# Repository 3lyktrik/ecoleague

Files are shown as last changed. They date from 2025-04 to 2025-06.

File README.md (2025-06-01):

# Ολοκληρωμένο σύστημα υποστήριξης διαγωνισμών ανακύκλωσης

Είμαστε η ομάδα **"Eco League"** από το **3ο ΓΕΛ Τρικάλων "Οδυσσέας Ελύτης"** και στα πλαίσια της συμμετοχής μας στον **"7ο Πανελλήνιο Διαγωνισμό Ανοιχτών Τεχνολογιών στην Εκπαίδευση"** υλοποιήσαμε το έργο **"Ολοκληρωμένο σύστημα υποστήριξης διαγωνισμών ανακύκλωσης"**.

## Το πρόβλημα

Ένα πολύ μεγάλο πρόβλημα των σύγχρονων κοινωνιών είναι το πρόβλημα της διαχείρισης των σκουπιδιών και της συγκέντρωσης των ανακυκλώσιμων υλικών από τους πολίτες.
Για διάφορους λόγους, πολλοί συμπολίτες μας δεν έχουν αναπτύξει κουλτούρα ανακύκλωσης και πετάνε ανακυκλώσιμα υλικά στους κοινούς κάδους απορριμμάτων, με αποτέλεσμα τόσο την περαιτέρω ρύπανση του περιβάλλοντος, όσο και τη σπατάλη πολύτιμων υλικών, που θα μπορούσαν να ξαναχρησιμοποιηθούν.

Δείτε αναλυτικά την **έρευνα** που κάναμε για αυτό το πρόβλημα στο [docs/Έρευνα.md](docs/Έρευνα.md).

## Η λύση
Για τη βελτίωση αυτής της κατάστασης υλοποιήσαμε ένα έξυπνο, αυτοματοποιημένο σύστημα υποστήριξης διαγωνισμών ανακύκλωσης.

Οι πολίτες που συμμετέχουν στο διαγωνισμό παίρνουν βαθμούς ανάλογα με τα υλικά που ανακυκλώνουν.

Τα υλικά ανιχνεύονται και καταγράφονται αυτόματα από το σύστημα, ενώ ταυτόχρονα οι ανάλογοι βαθμοί καταχωρούνται στο συγκεκριμένο πολίτη που τα ανακύκλωσε.

Κάθε ανακυκλώσιμο υλικό παίρνει συγκεκριμένους βαθμούς, οι οποίοι προστίθενται στη συνολική βαθμολογία του κάθε πολίτη.

Σε εβδομαδιαία βάση, οι πολίτες που ανακυκλώνουν τα περισσότερα υλικά και συγκεντρώνουν τη μεγαλύτερη βαθμολογία, αναδεικνύονται πρωταθλητές στην ανακύκλωση και βραβεύονται από το φορέα που διοργανώνει το διαγωνισμό.

Η ανακύκλωση γίνεται έτσι παιχνίδι, κίνητρο και διασκέδαση!

## Οι στόχοι

- Να κάνουμε την ανακύκλωση μέρος της καθημερινότητας με έναν ευχάριστο, δημιουργικό τρόπο.

- Να καλλιεργήσουμε την οικολογική συνείδηση μέσα από το παιχνίδι και τη συμμετοχή.

- Και φυσικά, να βοηθήσουμε έμπρακτα στην προστασία του περιβάλλοντος, γιατί η ανάγκη είναι μεγαλύτερη από ποτέ!

## Σχεδιασμός - Υλοποίηση

Το σύστημα αποτελείται από έξυπνους κάδους ανακύκλωσης, οι οποίοι ελέγχονται από Arduino και λειτουργούν ως εξής:

- Πρώτα γίνεται ταυτοποίηση του πολίτη με κάρτες RFID. Κάθε πολίτης προμηθεύεται μια κάρτα και αντιστοιχίζεται ο κωδικός της κάρτας με το όνομά του.
Κατόπιν γίνεται ανίχνευση του υλικού που τοποθετεί ο πολίτης στον κάδο (μέταλλο, γυαλί, πλαστικό ή άλλο υλικό) και υπολογίζονται οι βαθμοί που κερδίζει. Αρχικά, ο αισθητήρας μετάλλων ανιχνεύει τα μέταλλα. Στη συνέχεια, αν το υλικό δεν είναι μέταλλο, ενεργοποιείται το laser, το οποίο στοχεύει σε ένα φωτοκύτταρο. Αν το φωτοκύτταρο ενεργοποιηθεί, τότε το υλικό είναι διαφανές, δηλαδή γυαλί ή πλαστικό. Ενώ αν το laser δεν περάσει μέσα από το αντικείμενο, σημαίνει ότι αυτό δεν είναι διαφανές. Ο διαχωρισμός ανάμεσα στα δύο υλικά γίνεται μέσω της ζυγαριάς, καθώς το γυαλί είναι βαρύτερο από το πλαστικό.
- Μετά την ανίχνευση του υλικού, το σύστημα συνδέεται μέσω WiFi σε μια βάση δεδομένων που φτιάξαμε στο διαδίκτυο (στο ThingSpeak), όπου αποθηκεύεται η βαθμολογία κάθε πολίτη.
- Κατά τη διάρκεια της διαδικασίας εμφανίζονται όλες οι πληροφορίες σε μια οθόνη LCD.
- Παράλληλα αναπτύξαμε μια εφαρμογή για συσκευές Android, η οποία ανακτά όλες τις βαθμολογίες από τη βάση δεδομένων και εμφανίζει έναν αναλυτικό πίνακα (Hall Of Fame) με τις επιδόσεις όλων των πολιτών.

Δείτε αναλυτικά τη λύση μας, το σχεδιασμό και την υλοποίηση στο [docs/Σχεδιασμός.md](docs/Σχεδιασμός.md).

## Βίντεο
Βίντεο παρουσίασης (https://www.youtube.com/watch?v=4Vhta9W4wgw)

## Η ομάδα
Η ομάδα Eco League αποτελείται από τους μαθητές της Α΄ Τάξης του σχολείου:
Βράντζα Αθηνά, Κωτούλας Απόστολος, Παπαδάκη Δήμητρα, Παπαϊωάννου Χρήστος, Πλακιά Αναστασία, Πλεξίδας Βασίλειος, Ράπτης Αθανάσιος, Σουλιμέτσης Ελευθέριος, Στασινός Γεώργιος, Τσιγάρας Σεραφείμ, Τσιούκης Κομνηνός, Τσόγκα Νίκη και Χατζής Άγγελος.

Υπεύθυνος καθηγητής: Μαντζάνας Ευάγγελος

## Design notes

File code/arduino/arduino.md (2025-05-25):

Τα απαραίτητα αρχεία με τον κώδικα για Arduino.

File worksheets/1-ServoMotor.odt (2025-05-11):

# Φύλλο Εργασίας 1

# Κινητήρας Servo

## Δραστηριότητα 1

Μπείτε στο https://docs.arduino.cc/learn/electronics/servo-motors/ και κάντε τα παραδείγματα Knob και Sweep.

## Δραστηριότητα 2

Προγραμματίστε τον κινητήρα Servo έτσι ώστε να περιστρέφεται σε γωνία 90 μοιρών.

## Δραστηριότητα 3

Προγραμματίστε δύο συναρτήσεις με ονόματα turnServo1 και turnServo2, από τις οποίες η μία θα περιστρέφει το servo κατά περίπου 90 μοίρες, ενώ η άλλη θα το επαναφέρει στην αρχική του θέση.

### Ενδεικτική λύση:

void turnServo1(void)

{

for (int pos = 0; pos <= 120; pos++)

{

myservo.write(pos);

delay(10);

}

}

void turnServo2(void)

{

for (int pos = 120; pos >= 0; pos--)

{

myservo.write(pos);

delay(10);

}

}

## Δραστηριότητα 4

Μελετήστε τον τρόπο λειτουργίας του κινητήρα servo εδώ:

https://lastminuteengineers.com/servo-motor-arduino-tutorial/

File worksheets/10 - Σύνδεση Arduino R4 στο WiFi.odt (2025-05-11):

# Φύλλο Εργασίας 10

# Σύνδεση του Arduino UNO R4 - WiFi σε ένα ασύρματο δίκτυο

Πηγές:

1. https://docs.arduino.cc/tutorials/uno-r4-wifi/wifi-examples/#connect-with-wpa
2. https://www.halvorsen.blog/documents/technology/iot/thingspeak/thingspeak.php

Από τον παραπάνω σύνδεσμο 1, βρείτε το παράδειγμα “Connect With WPA” (μπορείτε να το ανοίξετε και από τα παραδείγματα του Arduino IDE, στη θέση: Αρχείο -> Παραδείγματα -> WiFiS3 -> ConnectWithWPA).

Στο αρχείο (ή στην καρτέλα) arduino_secrets.h πληκτρολογείστε το SSID και το password του δικού σας δικτύου WiFi.

Εκτελέστε το παράδειγμα και επαληθεύστε ότι το Arduino συνδέεται στο δίκτυο WiFi.

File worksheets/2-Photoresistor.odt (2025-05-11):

# Φύλλο Εργασίας 2

# Φωτοαντίσταση με Arduino

## Δραστηριότητα 1

Μπείτε στο https://www.circuitbasics.com/how-to-use-photoresistors-to-detect-light-on-an-arduino/

και κάντε το παράδειγμα με την αντίσταση των 220Ω.

## Δραστηριότητα 2

Μελετήστε τις τιμές που δίνει η φωτοαντίσταση (δηλαδή τις τιμές που διαβάζουμε στην αναλογική είσοδο). Προσπαθήστε να βρείτε τις οριακές τιμές της φωτοαντίστασης στο απόλυτο σκοτάδι (καλύπτοντάς την με το χέρι), ή σε έντονο φως (φωτίζοντάς την με ένα φακό). Καταγράψτε αυτές τις οριακές τιμές, όπως επίσης και την “κανονική” τιμή στον παρακάτω πίνακα.

## Δραστηριότητα 3

Συμπληρώστε ολόκληρο τον πίνακα, αλλάζοντας κατάλληλα την αντίσταση των 220Ω.

Α/Α | Αντίσταση | Τιμή που δίνει η φωτοαντίσταση σε κανονικές συνθήκες | Τιμή που δίνει η φωτοαντίσταση στο σκοτάδι | Τιμή που δίνει η φωτοαντίσταση σε έντονο φως
1 | 220Ω
2 | 1ΚΩ
3 | 2.2ΚΩ
4 | 10ΚΩ

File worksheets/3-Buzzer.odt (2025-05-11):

# Φύλλο Εργασίας 3

# Buzzer με Arduino

## Δραστηριότητα 1

Μπείτε στο https://www.ardumotive.com/how-to-use-a-buzzer-en.html και κάντε το παράδειγμα.

## Δραστηριότητα 2

Κάντε το buzzer να χτυπά πιο γρήγορα (πιο συχνά).

## Δραστηριότητα 3

Πειραματιστείτε με την τονικότητα του buzzer: κάντε το να χτυπά σε υψηλότερους ή χαμηλότερους τόνους.

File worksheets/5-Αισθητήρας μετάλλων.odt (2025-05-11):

Φύλλο Εργασίας 5

Αισθητήρας μετάλλων (επαγωγικός)

Πηγή: https://www.openbook.gr/efarmoges-arduino-sto-scholiko-ergastirio-gia-to-perivallon/

## Υλικά

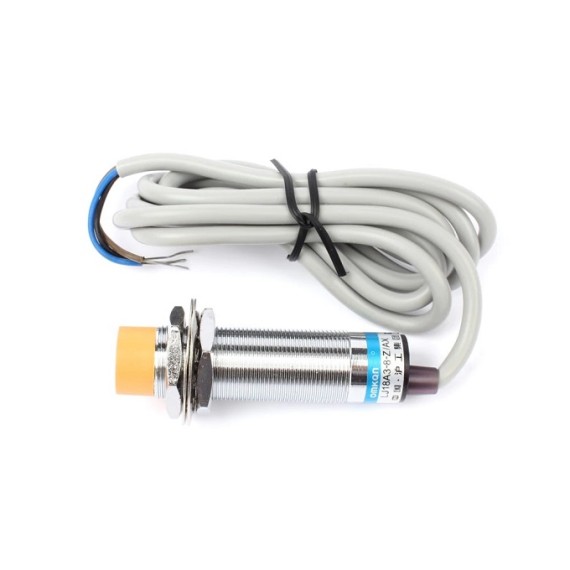
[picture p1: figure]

Επαγωγικός αισθητήρας μετάλλων LJ18A3-8-Z/AX

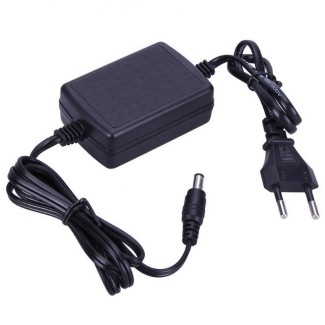
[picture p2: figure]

Τροφοδοτικό 12V

## Συνδεσμολογία

Καλώδιο αισθητήρα LJ18A3-8-Z/AX | Σύνδεση
Μπλε | Γείωση (GND). Προσοχή: η γείωση της εξωτερικής τροφοδοσίας να συνδέεται με τη γείωση του arduino.
Καφέ | 12V (από εξωτερική τροφοδοσία)
Μαύρο | Σήμα (pin 11 του Arduino, με ενεργοποιημένη την εσωτερική pull-up αντίσταση)

## Δραστηριότητα 1

Δημιουργήστε έναν ανιχνευτή μετάλλων: όταν ο αισθητήρας πλησιάσει κάποιο μέταλλο, να ανάβει το ενσωματωμένο LED του Arduino.

## Δραστηριότητα 2

Δοκιμάστε διάφορα μέταλλα (αλουμίνιο, σίδερο, ατσάλι κλπ) και σημειώστε την απόσταση από τον αισθητήρα που ανιχνεύεται το μέταλλο σε κάθε περίπτωση.

## Κώδικας

const int sensorPin = 11;

int sensorVal; // το σήμα του αισθητήρα

void setup()

{

pinMode(sensorPin, INPUT_PULLUP);

}

void loop()

{

sensorVal = digitalRead(sensorPin);

if( sensorVal == HIGH )

{

digitalWrite(LED_BUILTIN, HIGH);

}

else

{

digitalWrite(LED_BUILTIN, LOW);

}

delay(100);

}

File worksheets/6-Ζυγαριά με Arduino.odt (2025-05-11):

# Φύλλο Εργασίας 6

# Ζυγαριά με Arduino

Πηγή: https://randomnerdtutorials.com/arduino-load-cell-hx711/

## Υλικά

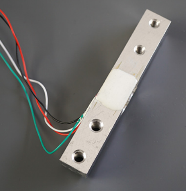
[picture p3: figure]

Αισθητήρας φορτίου (load cell)

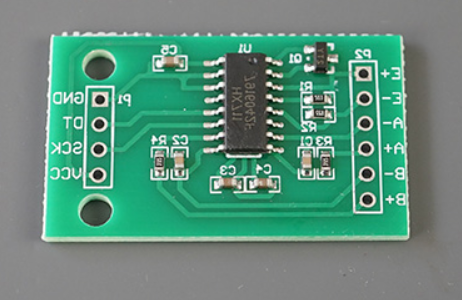
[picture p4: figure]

Ενισχυτής φορτίου HX711

## Κατασκευή ζυγαριάς

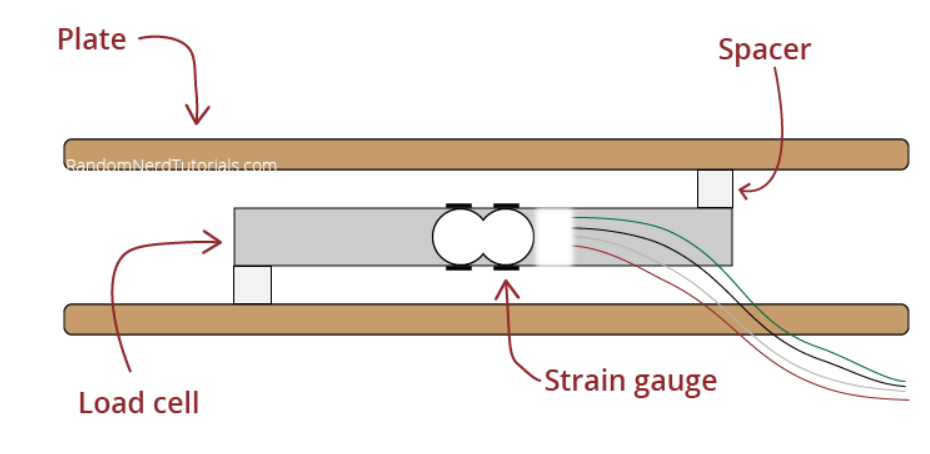
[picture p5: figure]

## Συνδεσμολογία

Αισθητήρας φορτίου | HX711 | HX711 | Arduino
Κόκκινο (Ε+) | Ε+ | GND | GND
Μαύρο (Ε-) | Ε- | DT | Pin 2
Άσπρο (Α-) | Α- | SCK | Pin 3
Πράσινο (Α+) | Α+ | VCC | 5V

## Κύκλωμα

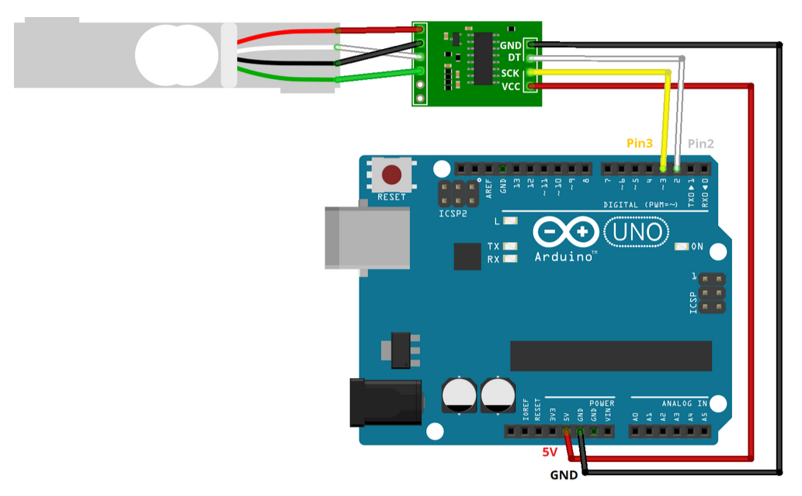
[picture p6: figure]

## Βιβλιοθήκη

Στο Arduino IDE εγκαταστήστε τη βιβλιοθήκη “HX711 Arduino Library” του Bogdan Necula.

## Πρόγραμμα για καλιμπράρισμα

// Calibrating the load cell

#include "HX711.h"

// HX711 circuit wiring

const int LOADCELL_DOUT_PIN = 2;

const int LOADCELL_SCK_PIN = 3;

HX711 scale;

void setup()

{

Serial.begin(115200);

scale.begin(LOADCELL_DOUT_PIN, LOADCELL_SCK_PIN);

}

void loop()

{

if (scale.is_ready())

{

scale.set_scale();

Serial.println("Καλιμπράρισμα Ζυγαριάς");

Serial.println("Απόβαρο... Αδειάστε τη ζυγαριά.");

delay(5000);

scale.tare();

Serial.println("Απόβαρο ρυθμίστηκε.");

Serial.println("Τοποθετήστε ένα γνωστό βάρος στη ζυγαριά...");

delay(5000);

long reading = scale.get_units(10);

Serial.print("Αποτέλεσμα: ");

Serial.println(reading);

Serial.println("Συντελεστής = (αποτέλεσμα) / (γνωστό βάρος)");

Serial.println();

}

else

{

Serial.println("HX711 δεν βρέθηκε.");

}

delay(1000);

}

## Πρόγραμμα ζυγαριάς

#include "HX711.h"

// HX711 circuit wiring

const int LOADCELL_DOUT_PIN = 2;

const int LOADCELL_SCK_PIN = 3;

HX711 scale;

void setup()

{

Serial.begin(115200);

Serial.println("Ζυγαριά");

scale.begin(LOADCELL_DOUT_PIN, LOADCELL_SCK_PIN);

// ο παρακάτω συντελεστής υπολογίστηκε με το καλιμπράρισμα

scale.set_scale(1095.56);

scale.tare(); // reset the scale to 0

delay(1000);

}

void loop()

{

if (scale.is_ready())

{

Serial.print("Βάρος (σε gr):\t");

Serial.println(scale.get_units(), 1);

}

else

{

Serial.println("Το HX711 δεν βρέθηκε.");

}

delay(3000);

}

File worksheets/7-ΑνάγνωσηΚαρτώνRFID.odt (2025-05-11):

# Φύλλο Εργασίας 7

# Ανάγνωση - Εγγραφή Καρτών RFID

Πηγή: https://lastminuteengineers.com/how-rfid-works-rc522-arduino-tutorial/

## Υλικά

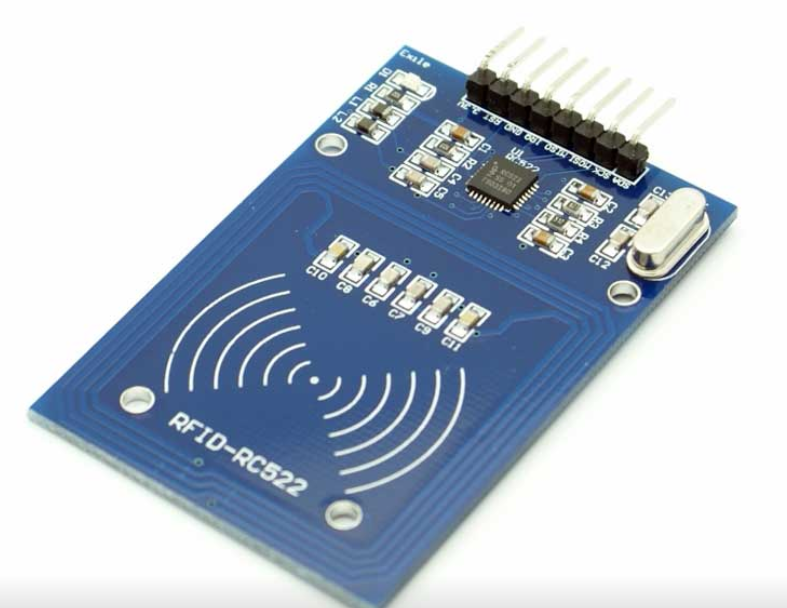
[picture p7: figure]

Αναγνώστης RFID - MFRC-522

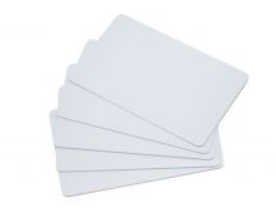
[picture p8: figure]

Κάρτες RFID 13.56MHz

## Συνδεσμολογία

RC522 πλακέτα | Arduino
Vcc | 3.3V
GND | GND
RST | Pin 5
MISO / SCL / Tx | Pin 12
MOSI | Pin 11
SCK | Pin 13
SS / SDA / Rx | Pin 10

## Κύκλωμα

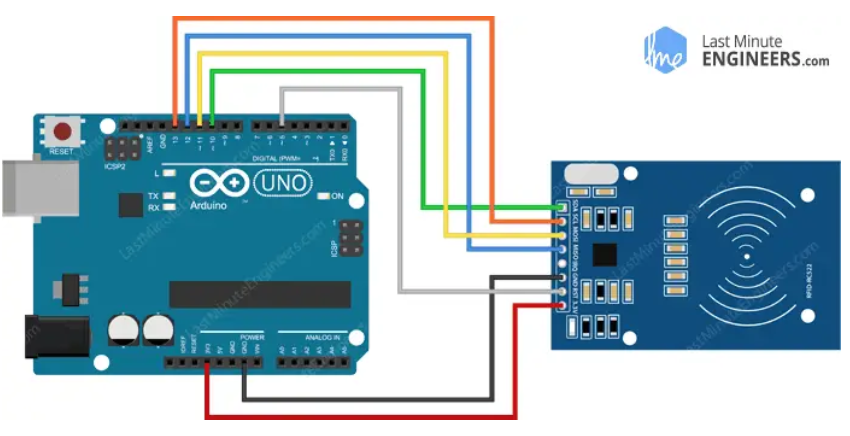
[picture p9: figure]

## Βιβλιοθήκη

Στο Arduino IDE εγκαταστήστε τη βιβλιοθήκη MFRC522 by GithubCommunity.

## Πρόγραμμα 1: Ανάγνωση όλων των δεδομένων από την κάρτα

#include <SPI.h>

#include <MFRC522.h>

#define RST_PIN 5

#define SS_PIN 10

MFRC522 mfrc522(SS_PIN, RST_PIN);

void setup()

{

Serial.begin(115200); // για serial monitor

while (!Serial); // Do nothing if no serial port is opened

SPI.begin(); // Init SPI bus

mfrc522.PCD_Init(); // Init MFRC522 card reader

delay(4);

mfrc522.PCD_DumpVersionToSerial(); // Show details of MFRC522

Serial.println("Scan PICC to see UID, SAK, type, and data blocks...");

}

void loop()

{

// Check for new card present on the reader.

if ( ! mfrc522.PICC_IsNewCardPresent() )

return;

// Select one of the cards

if ( ! mfrc522.PICC_ReadCardSerial() )

return;

// Dump debug info about the card; PICC_HaltA() is automatically called

mfrc522.PICC_DumpToSerial(&(mfrc522.uid));

}

## Πρόγραμμα 2: Έλεγχος πρόσβασης με κάρτες RFID

#include <SPI.h>

#include <MFRC522.h>

#define RST_PIN 5

#define SS_PIN 10

byte readCard[4];

String MasterTag = "931A9628"; // REPLACE this Tag ID with your Tag ID!!!

String tagID = "";

MFRC522 mfrc522(SS_PIN, RST_PIN);

void setup()

{

Serial.begin(115200); // Serial monitor

SPI.begin(); // SPI bus

mfrc522.PCD_Init(); // MFRC522

Serial.println(" -- Access Control -- ");

Serial.print("MasterTag:");

Serial.println(MasterTag);

Serial.println("Scan Your Card>>>");

}

void loop()

{

// Wait until new tag is available

while( getID() )

{

if( tagID == MasterTag )

{

Serial.println("Access Granted!");

}

else

{

Serial.println("Access Denied...");

}

Serial.print("ID: ");

Serial.println(tagID);

delay(500);

Serial.println(" -- Access Control -- ");

Serial.print("MasterTag:");

Serial.println(MasterTag);

Serial.println("Scan Your Card>>>");

}

}

// Read new tag if available

boolean getID()

{

// Getting ready for Reading PICCs

if( !mfrc522.PICC_IsNewCardPresent() )

{

return false;

}

if( !mfrc522.PICC_ReadCardSerial() )

{

return false;

}

tagID = "";

for( int i = 0; i < mfrc522.uid.size; i++ )

{

tagID.concat(String(mfrc522.uid.uidByte[i], HEX)); // Adds the bytes in a single String variable

}

tagID.toUpperCase();

mfrc522.PICC_HaltA(); // Stop reading

return true;

}

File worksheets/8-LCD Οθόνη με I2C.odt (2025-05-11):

Φύλλο Εργασίας 8

Οθόνη LCD με σύνδεση I2C

Δραστηριότητα

Κάντε το tutorial https://lastminuteengineers.com/i2c-lcd-arduino-tutorial/

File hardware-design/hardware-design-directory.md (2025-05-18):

Εδώ βρίσκονται τα σχέδια του κυκλώματος και των αντικειμένων 3D.

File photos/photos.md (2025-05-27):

## Φωτογραφίες από τη δημιουργία του έργου.
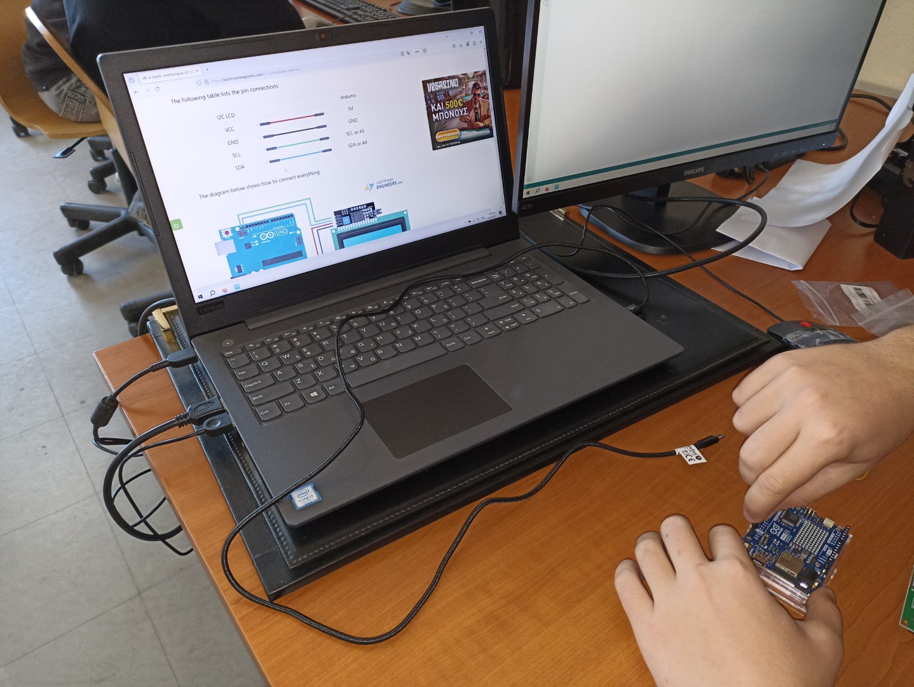
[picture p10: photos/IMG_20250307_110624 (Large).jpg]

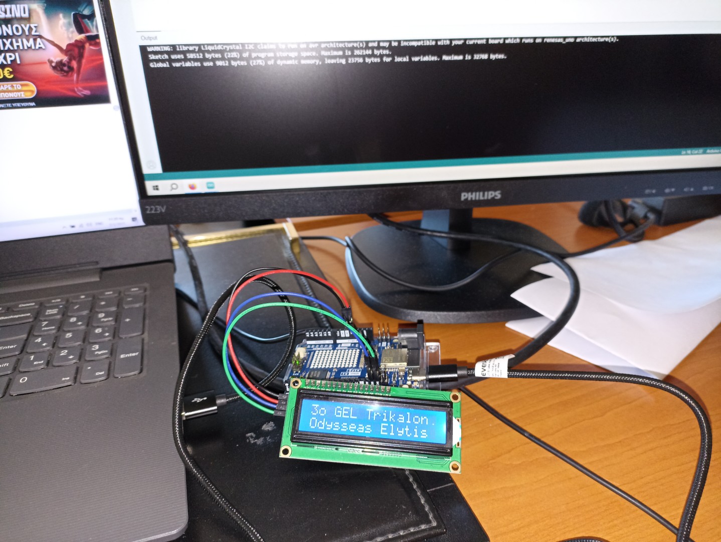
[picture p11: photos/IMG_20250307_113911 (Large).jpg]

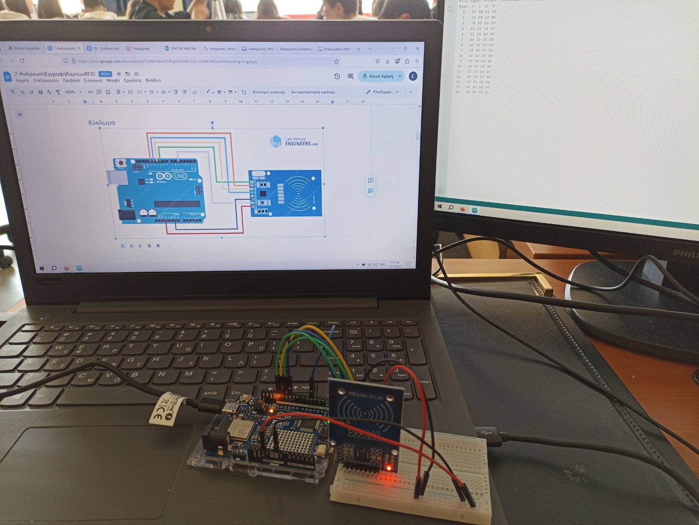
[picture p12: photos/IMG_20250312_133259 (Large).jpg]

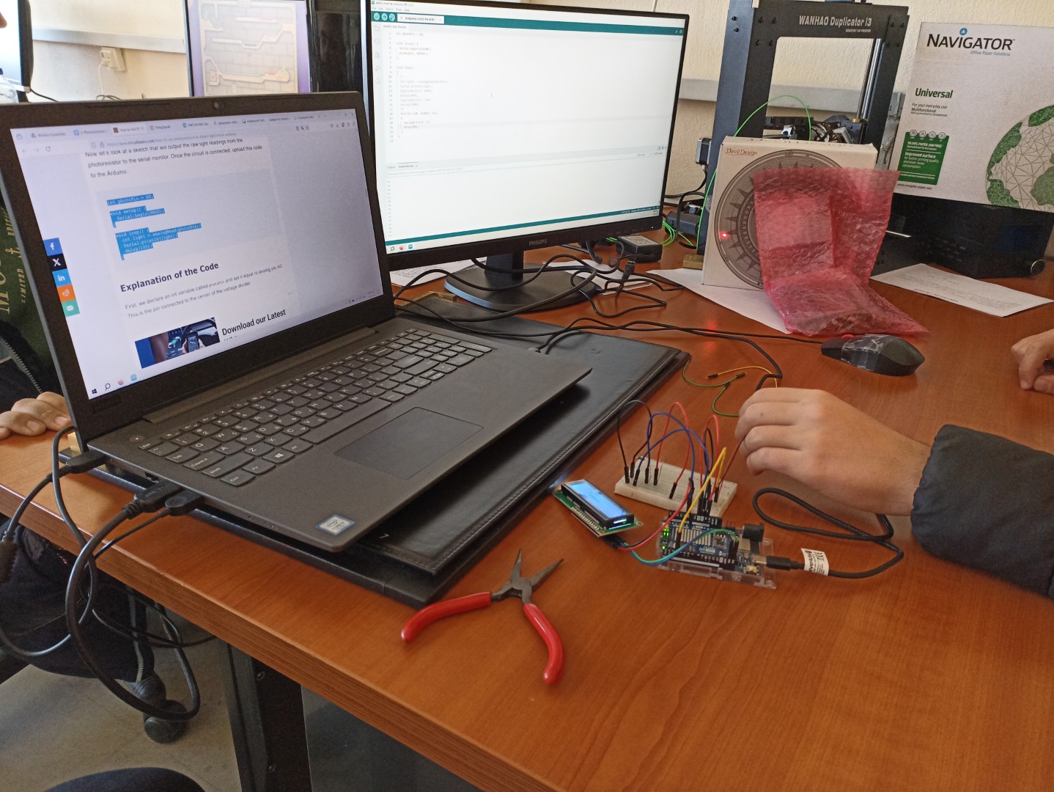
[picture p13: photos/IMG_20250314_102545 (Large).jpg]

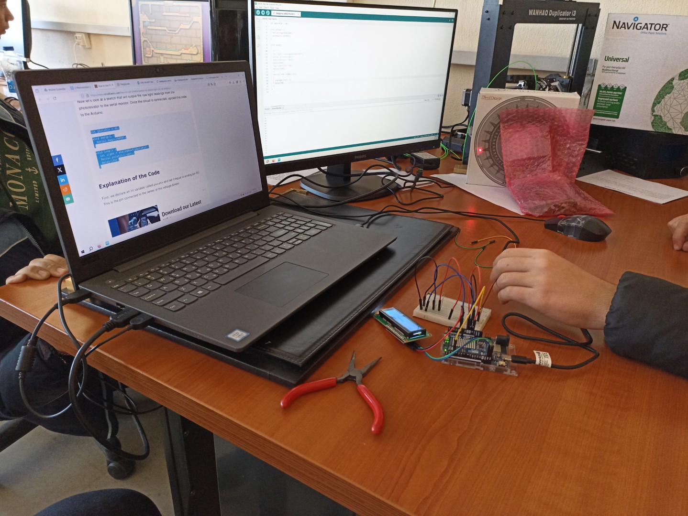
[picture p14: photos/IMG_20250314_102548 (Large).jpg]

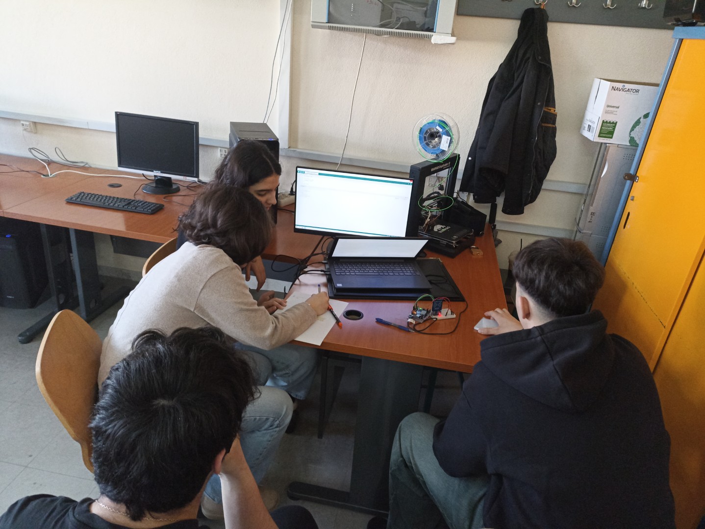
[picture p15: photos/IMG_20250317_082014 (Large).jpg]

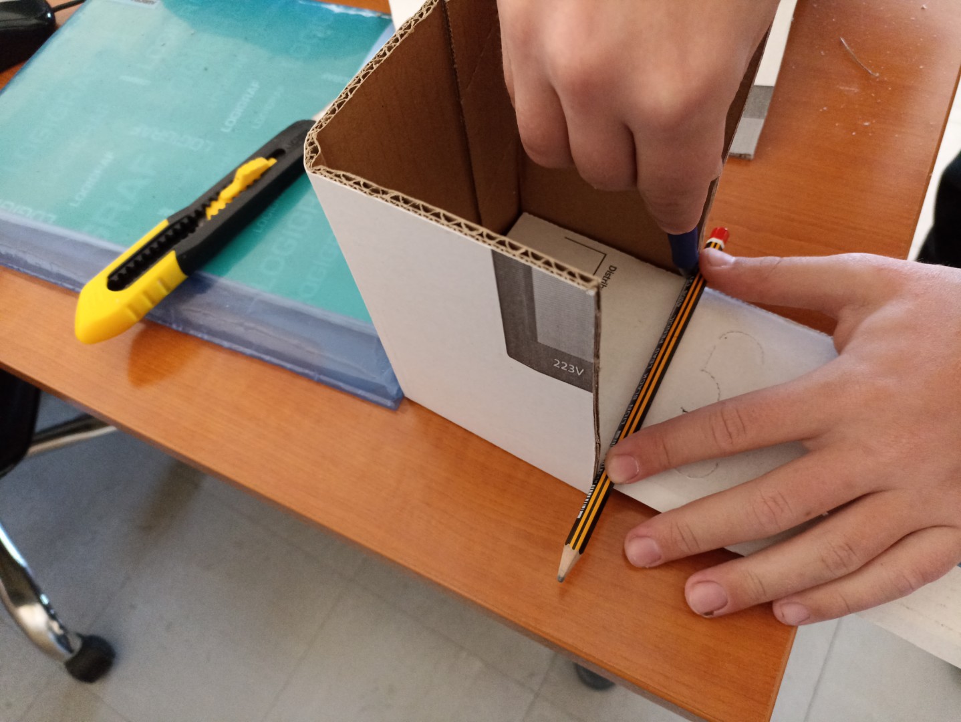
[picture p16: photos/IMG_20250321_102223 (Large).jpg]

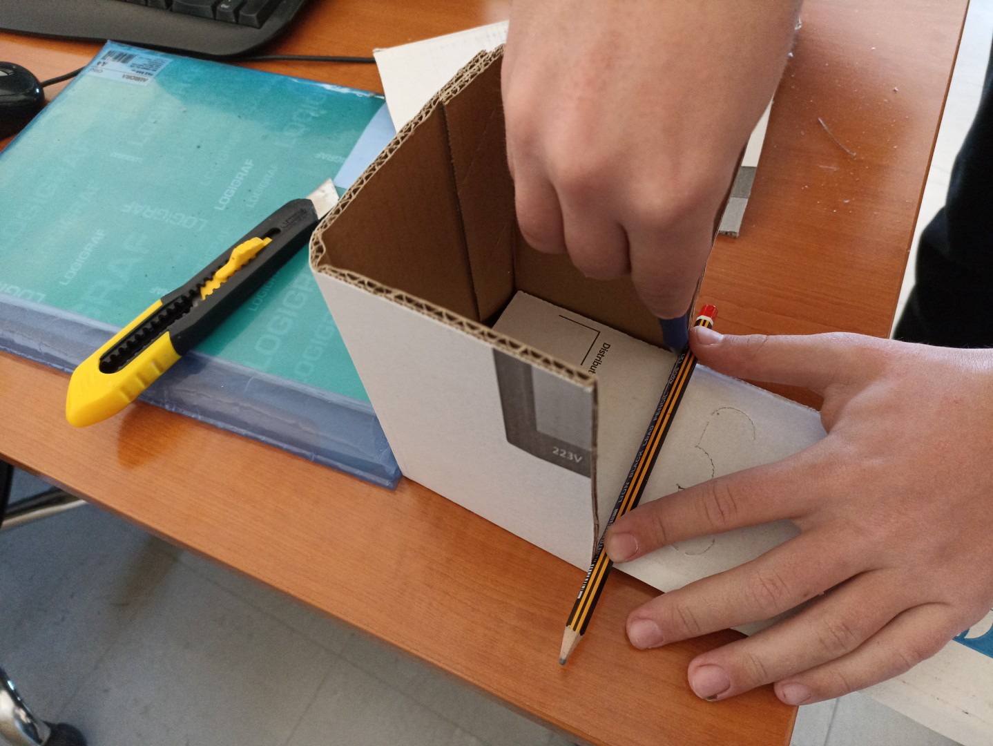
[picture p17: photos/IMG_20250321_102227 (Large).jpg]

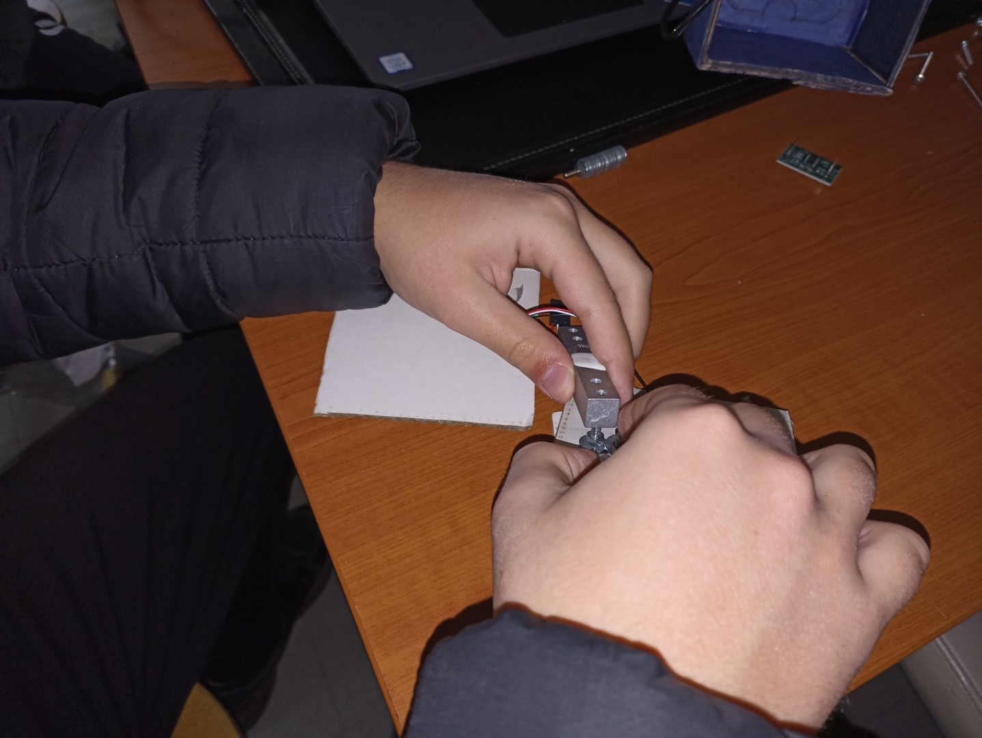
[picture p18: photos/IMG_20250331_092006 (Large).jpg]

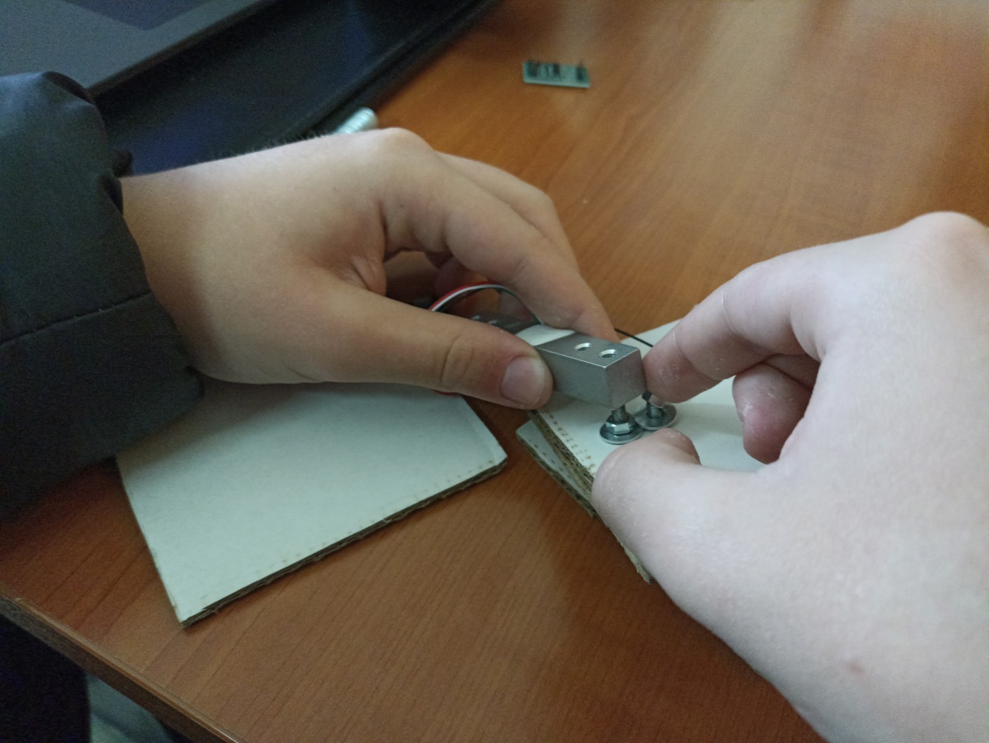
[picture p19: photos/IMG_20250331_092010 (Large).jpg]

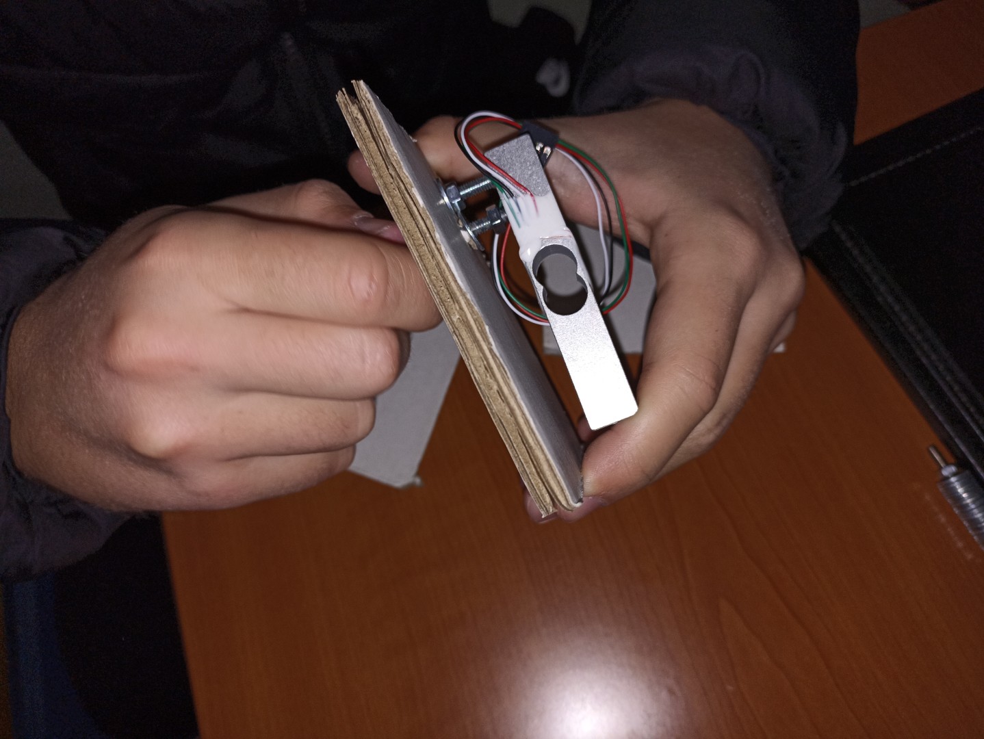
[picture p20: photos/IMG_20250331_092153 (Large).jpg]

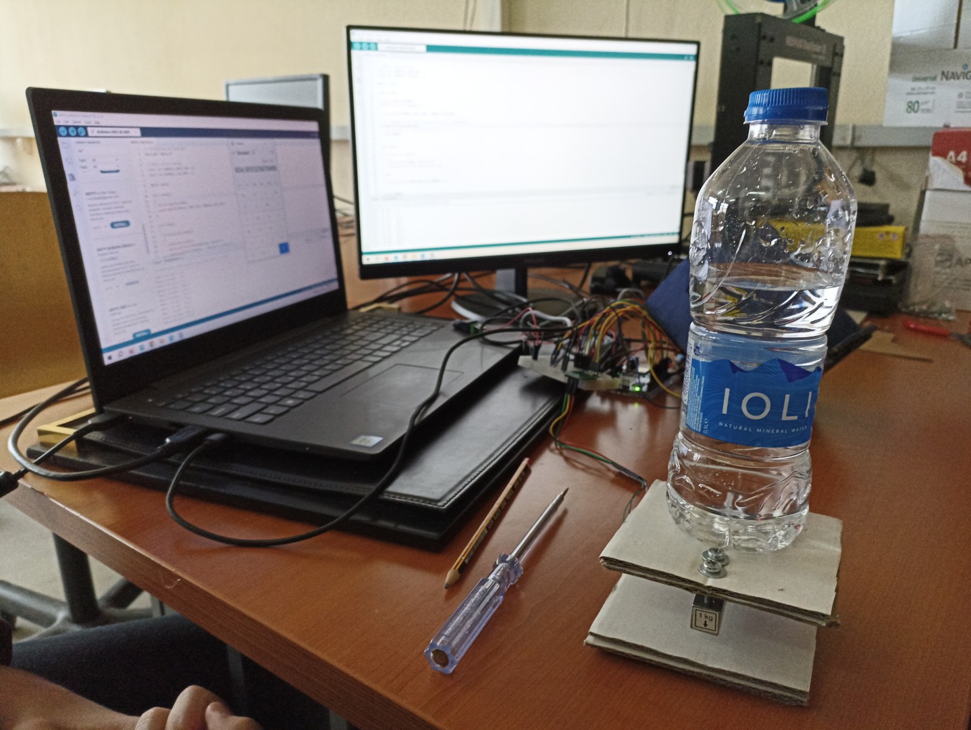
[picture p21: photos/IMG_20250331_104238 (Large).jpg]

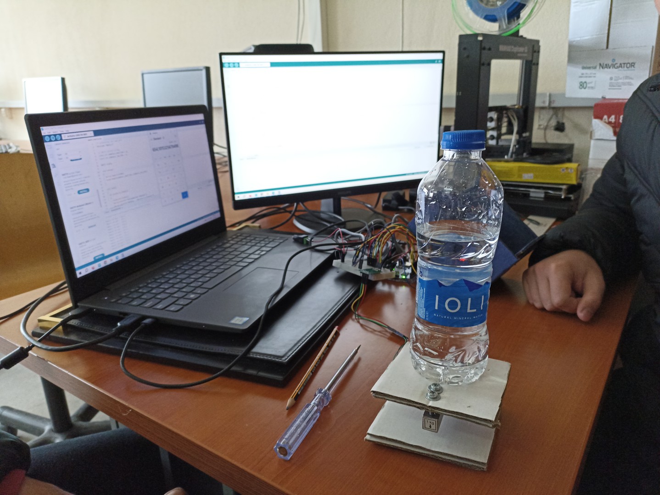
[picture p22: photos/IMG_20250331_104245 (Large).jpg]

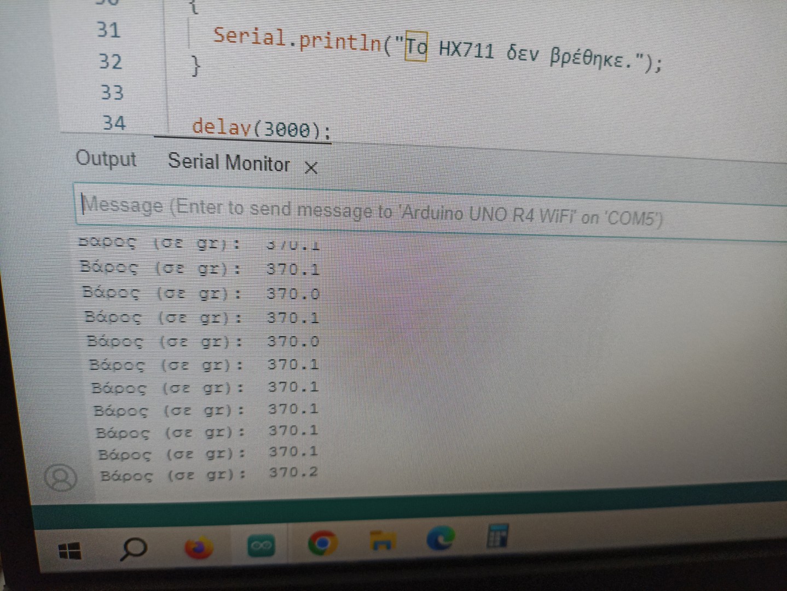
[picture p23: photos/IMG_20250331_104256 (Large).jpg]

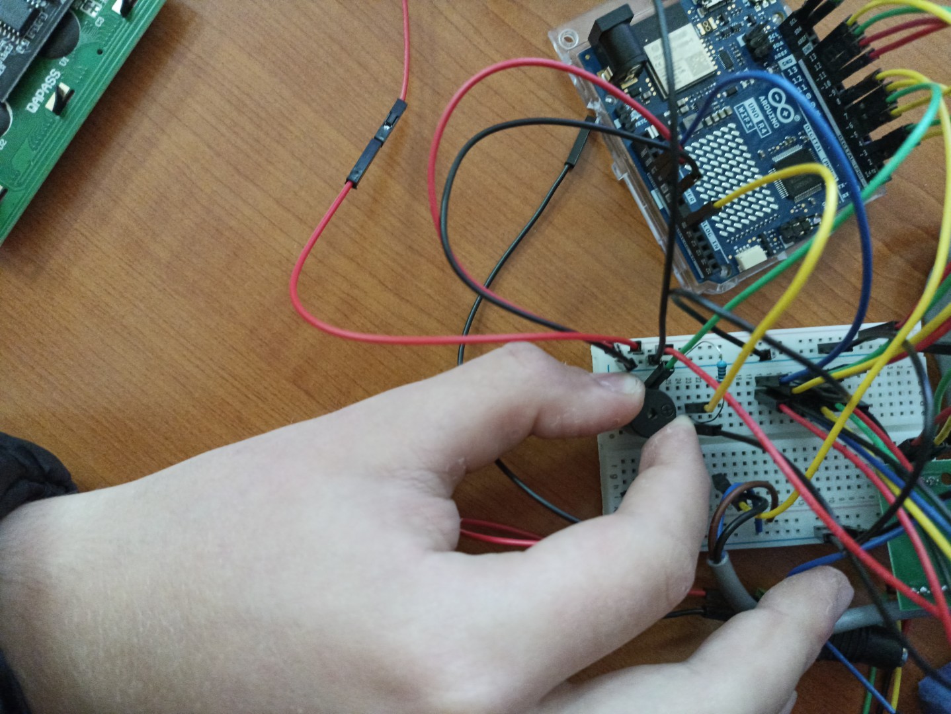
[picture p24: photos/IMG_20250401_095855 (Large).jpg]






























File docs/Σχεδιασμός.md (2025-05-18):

# Σχεδιασμός

## Σαφής ορισμός προτεινόμενης λύσης

### Λύση

Για την αύξηση της συμμετοχής των πολιτών στην ανακύκλωση, υλοποιήσαμε ένα έξυπνο, αυτοματοποιημένο σύστημα υποστήριξης διαγωνισμών ανακύκλωσης.

Οι πολίτες που θα συμμετέχουν στο διαγωνισμό ανακύκλωσης, παίρνουν βαθμούς ανάλογα με τα υλικά που ανακυκλώνουν.

Τα υλικά ανιχνεύονται και καταγράφονται αυτόματα από το σύστημα, ενώ ταυτόχρονα οι ανάλογοι βαθμοί καταχωρούνται στο συγκεκριμένο πολίτη που τα ανακύκλωσε.

Κάθε ανακυκλώσιμο υλικό παίρνει συγκεκριμένους βαθμούς, οι οποίοι προστίθενται στη συνολική βαθμολογία του κάθε πολίτη.

Σε εβδομαδιαία βάση, οι πολίτες που ανακυκλώνουν τα περισσότερα υλικά και συγκεντρώνουν τη μεγαλύτερη βαθμολογία, αναδεικνύονται πρωταθλητές στην ανακύκλωση και βραβεύονται από το φορέα που διοργανώνει το διαγωνισμό.

### Οι στόχοι

-   Να κάνουμε την ανακύκλωση μέρος της καθημερινότητας με έναν ευχάριστο, δημιουργικό τρόπο.

-   Να καλλιεργήσουμε την οικολογική συνείδηση μέσα από το παιχνίδι και τη συμμετοχή.

-   Και φυσικά, να βοηθήσουμε έμπρακτα στην προστασία του περιβάλλοντος, γιατί η ανάγκη είναι μεγαλύτερη από ποτέ!

### Σχεδιασμός - Υλοποίηση

Το σύστημα αποτελείται από έξυπνους κάδους ανακύκλωσης, οι οποίοι ελέγχονται από Arduino και λειτουργούν ως εξής:

1.  Πρώτα γίνεται ταυτοποίηση του πολίτη με κάρτες RFID. Κάθε πολίτης προμηθεύεται μια κάρτα και αντιστοιχίζεται ο κωδικός της κάρτας με το όνομά του.

2.  Κατόπιν γίνεται ανίχνευση του υλικού που τοποθετεί ο πολίτης στον κάδο (μέταλλο, γυαλί, πλαστικό ή άλλο υλικό) και υπολογίζονται οι βαθμοί που κερδίζει. Ορίσαμε 50 βαθμούς για τα μέταλλα, 40 για τα πλαστικά και 30 για το γυαλί. Για την ανίχνευση, αρχικά ο αισθητήρας μετάλλων ανιχνεύει τα μέταλλα. Στη συνέχεια, αν το υλικό δεν είναι μέταλλο, ενεργοποιείται το laser, το οποίο στοχεύει σε ένα φωτοκύτταρο (το laser με το φωτοκύτταρο πρέπει να είναι ευθυγραμμισμένα). Αν το φωτοκύτταρο ενεργοποιηθεί, τότε το υλικό είναι διαφανές, δηλαδή γυαλί ή πλαστικό. Ενώ αν το laser δεν περάσει μέσα από το αντικείμενο, σημαίνει ότι αυτό δεν είναι διαφανές. Ο διαχωρισμός ανάμεσα στα δύο υλικά γίνεται μέσω της ζυγαριάς, καθώς το γυαλί είναι βαρύτερο από το πλαστικό. Θέσαμε ως όριο τα 100gr: πάνω από 100gr θεωρείται γυαλί, αλλιώς πλαστικό.

3.  Μετά την ανίχνευση του υλικού, το σύστημα συνδέεται μέσω WiFi σε μια βάση δεδομένων που φτιάξαμε στο διαδίκτυο (στο ThingSpeak), όπου αποθηκεύεται η βαθμολογία κάθε πολίτη. Το σύστημα διαβάζει την τρέχουσα βαθμολογία του πολίτη, προσθέτει τους βαθμούς ανακύκλωσης ανάλογα με το υλικό και στέλνει τη νέα βαθμολογία πάλι στη βάση δεδομένων.

4.  Κατά τη διάρκεια της διαδικασίας εμφανίζονται όλες οι πληροφορίες (το όνομα του πολίτη, οι βαθμοί από το υλικό που ανακύκλωσε, καθώς και οδηγίες) σε μια οθόνη LCD.

Παράλληλα αναπτύξαμε μια εφαρμογή για συσκευές Android, η οποία ανακτά όλες τις βαθμολογίες από τη βάση δεδομένων και εμφανίζει έναν αναλυτικό πίνακα (Hall Of Fame) με τις επιδόσεις όλων των πολιτών.

## Πρωτοτυπία της λύσης μας

Η λύση μας ξεχωρίζει γιατί **συνδυάζει τρεις βασικούς άξονες που δεν
συναντώνται συνήθως μαζί** σε υπάρχοντα συστήματα ανακύκλωσης:

1.  **Αυτοματοποιημένη αναγνώριση ανακυκλώσιμων υλικών:**\
    Το σύστημά μας χρησιμοποιεί έξυπνες τεχνολογίες (π.χ. μέτρηση βάρους, ανίχνευση διαφάνειας, ταυτοποίηση με κάρτες) ώστε να καταγράφει **αυτόματα** τα υλικά χωρίς την ανάγκη **χειροκίνητης** παρέμβασης.

2.  **Ατομική βαθμολόγηση πολιτών:**\
    Η κάθε ενέργεια ανακύκλωσης **καταχωρείται στο προφίλ του συγκεκριμένου πολίτη**, κάτι που **σπάνια συναντάται** σε υπάρχοντα συστήματα ανακύκλωσης. Έτσι, αναδεικνύεται η ατομική προσπάθεια και όχι μόνο η συλλογική.

4.  **Διαγωνιστική λογική και επιβράβευση:**\
    Με την εβδομαδιαία ανακοίνωση "πρωταθλητών ανακύκλωσης", το σύστημα προσφέρει **κίνητρο μέσω υγιούς ανταγωνισμού**, δημιουργώντας μια διαδραστική, παιχνιδοποιημένη εμπειρία που **κάνει την ανακύκλωση πιο ελκυστική** - ειδικά για τις νεότερες ηλικίες.

Επιπλέον, το σύστημά μας έχει σχεδιαστεί ώστε να μπορεί:

-   Να **προσαρμοστεί εύκολα** στις ανάγκες ενός σχολείου, ενός δήμου ή μιας γειτονιάς.

-   Να **συνδεθεί με εφαρμογές για κινητά**, ώστε οι πολίτες να παρακολουθούν την πρόοδό τους σε πραγματικό χρόνο.

Έτσι, δεν πρόκειται απλώς για μια τεχνολογική λύση, αλλά για ένα **κοινωνικό εργαλείο αλλαγής συμπεριφοράς**, που ενισχύει την περιβαλλοντική συνείδηση με τρόπο **καινοτόμο, προσιτό και διασκεδαστικό**.

## Κόστος

Το κόστος των αυτοματισμών για έναν κάδο είναι περίπου 90€.

## Λίστα υλικών και εργαλείων

Για την υλοποίηση του project (για έναν κάδο) χρησιμοποιήθηκαν τα
παρακάτω υλικά:

|**Α/Α**|  **Είδος** | **Τιμή** | **Τεμάχια** |  **Σύνολο**|
|----|---|---|---|---|
|  1 |  Arduino Uno R4 - WiFi | 32,80 € | 1 | 32,80 €|
|  2 | Καλώδιο USB type-C | 3,20 € | 1 | 3,20 €|
|  3 | Breadboard | 2,20 € | 1 | 2,20 €|
|  4 | Καλώδια breadboard Μ-Μ (δεκάδα) | 1,80 € | 2 | 3,60 €|
|  5 |  Καλώδια breadboard F-Μ (δεκάδα)  |  1,80 € | 2 | 3,60 €|
|  6 | Τροφοδοτικό 12V -- 1A | 3,80 € | 1 | 3,80 €|
|  7 | Οθόνη 16x2 Character LCD - (I2C Protocol) |  5,90 € | 1 | 5,90 €|
|  8 | Αναγνώστης καρτών RFID - MFRC-522 | 5,90 € | 1 | 5,90 €|
|  9 | Κάρτες RFID 13.56MHz | 0,80 € | 8 | 6,40 €|
|  10 |  Αισθητήρας φορτίου (load cell)  1Kgr  |  4,80 € | 1 | 4,80 €|
|  11 |  Ενισχυτής αισθητήρα φορτίου HX711 | 1,90 € | 1 | 1,90 €|
|  12 |  Επαγωγικός αισθητήρας 18mm - LJ18A3-8-Z/BX  |  5,90 € | 1 | 5,90 €|
|  13 |  Φωτοαντίσταση LDR 5mm | 0,20 € | 1 | 0,20 €|
|  14 |  Laser | 2,60 € | 1 | 2,60 €|
|  15 |  Buzzer | 0,40 € | 1 | 0,40 €|
|  16 |  Αντίσταση 100Ω | 0,02 € | 1 | 0,02 €|
|  17 |  Αντίσταση 1ΚΩ | 0,02 € | 1 | 0,02 €|
|  18 |  Νήμα 1,75 mm - 0.5Kgr | 9,00 € | 1 | 9,00 €| 
| | | **ΓΕΝΙΚΟ ΣΥΝΟΛΟ:** | |  92,24 €|

## Σχέδια

### Κύκλωμα

Κύκλωμα

### Θήκη (Case)

Σχεδιάσαμε στο TinkerCAD και εκτυπώσαμε στον 3D εκτυπωτή μια θήκη για τη
συσκευή μας, πάνω στην οποία προσαρμόζονται όλοι οι αισθητήρες, καθώς
και το δίσκο της ζυγαριάς.

Τα σχέδια της τελευταίας έκδοσης της θήκης σε μορφή αρχείων stl μπορείτε
να τα δείτε [εδώ](/hardware-design/3D-objects).

Θήκη

Δίσκος

## Βασικός αλγόριθμος

Βασικός Αλγόριθμος

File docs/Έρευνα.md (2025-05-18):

## **Έρευνα**

### **α. Μελέτη υπάρχουσας κατάστασης**

Η ανακύκλωση αποτελεί μια από τις πιο σημαντικές πρακτικές για την προστασία του περιβάλλοντος, καθώς συμβάλλει στη μείωση της ρύπανσης, στην εξοικονόμηση φυσικών πόρων και στην περιορισμένη παραγωγή απορριμμάτων.

Μέσα από τη διαδικασία της ανακύκλωσης, υλικά όπως το χαρτί, το πλαστικό, το γυαλί και τα μέταλλα επαναχρησιμοποιούνται, μειώνοντας την ανάγκη για εξόρυξη πρώτων υλών και την ενεργειακή κατανάλωση.

Επιπλέον, η ανακύκλωση συμβάλλει στη μείωση των εκπομπών αερίων του θερμοκηπίου και στην καταπολέμηση της κλιματικής αλλαγής.

Η ενεργός συμμετοχή των πολιτών σε αυτή τη διαδικασία είναι συνεπώς **απαραίτητη**.

Ωστόσο, η συμμετοχή των πολιτών στην ανακύκλωση στην Ελλάδα παραμένει περιορισμένη, όπως αποδεικνύεται από διάφορες έρευνες και στατιστικά στοιχεία:

1.  **Χαμηλά ποσοστά ανακύκλωσης σε εθνικό επίπεδο**: Μόνο το 19,9% των αστικών στερεών αποβλήτων ανακυκλώνεται ή κομποστοποιείται στην Ελλάδα, ενώ το 77,6% καταλήγει σε χωματερές. Αυτό το ποσοστό είναι από τα υψηλότερα στην ΕΕ, με τον ευρωπαϊκό μέσο όρο να είναι σημαντικά χαμηλότερος. ([CSRΝews.gr](https://csrnews.gr/58150/ereyna-dianeosis-poso-kykliki-einai-i))

2.  **Έλλειψη ενημέρωσης και κατανόησης**: Σύμφωνα με πανευρωπαϊκή έρευνα, το 77% των Ελλήνων νιώθει ότι δεν είναι καλά ενημερωμένο σχετικά με τη διαδικασία ανακύκλωσης, ενώ το 51% δεν γνωρίζει ποια απορρίμματα μπορούν να ανακυκλωθούν. ([LiFO](https://www.lifo.gr/now/perivallon/paneyropaiki-ereyna-96-ton-ellinon-zita-perissoteroys-kadoys-anakyklosis-se))

3.  **Περιορισμένη καθημερινή συμμετοχή**: Αν και το 86% των Ελλήνων ανακυκλώνει τουλάχιστον μία φορά τον μήνα, μόνο το 58% το κάνει καθημερινά. Επιπλέον, το 12% δεν ανακυκλώνει καθόλου, με το 11% να θεωρεί ότι \"δεν αξίζει τον κόπο\". ([Καθημερινή](https://www.kathimerini.gr/life/environment/777083/i-anakyklosi-kerdizei-edafos-stin-ellada/))

4.  **Δυσκολίες στην αναγνώριση συμβόλων ανακύκλωσης**: Μόνο το 25% των νέων ηλικίας 16-24 ετών γνωρίζει τη σημασία των συμβόλων ανακύκλωσης, ενώ σε μικρές κοινότητες κάτω των 1.000 κατοίκων, μόνο το 20% αναγνωρίζει όλα τα σήματα ανακύκλωσης. ([LiFO](https://www.lifo.gr/now/perivallon/paneyropaiki-ereyna-96-ton-ellinon-zita-perissoteroys-kadoys-anakyklosis-se))

5.  **Περιορισμένη ανακύκλωση εκτός σπιτιού**: Ενώ το 81% των Ελλήνων ανακυκλώνει συσκευασίες στο σπίτι, τα ποσοστά πέφτουν σημαντικά όταν βρίσκονται εκτός σπιτιού, όπως στη δουλειά (59%), στις μετακινήσεις (58%) και σε πάρκα ή παραλίες (55%). Η έλλειψη κάδων ανακύκλωσης σε δημόσιους χώρους αναφέρεται ως κύριος λόγος. ([Every Can Counts](https://everycancounts.eu/tag/%CE%B1%CE%BD%CE%B1%CE%BA%CF%8D%CE%BA%CE%BB%CF%89%CF%83%CE%B7/))

Αυτά τα στοιχεία δείχνουν την ανάγκη για ενίσχυση της ενημέρωσης, βελτίωση των υποδομών και παροχή κινήτρων για την αύξηση της συμμετοχής των πολιτών στην ανακύκλωση.

### **β. Σαφής ορισμός προβλήματος -- ανάγκης**

Συνεπώς το πρόβλημα που εντοπίσαμε είναι το εξής:

> Οι πολίτες δεν έχουν άμεσο, ορατό **κίνητρο** να συμμετέχουν συστηματικά στην ανακύκλωση, και η συνεισφορά τους **δεν καταγράφεται ούτε αναγνωρίζεται** με τρόπο που να ενθαρρύνει τη συνέχιση της προσπάθειας.

Οπότε προκύπτουν οι εξής ανάγκες:

-   Δημιουργία ενός **συστήματος που να επιβραβεύει** **αυτόματα** την ατομική συνεισφορά στην ανακύκλωση.

-   Ανάπτυξη ενός **παιχνιδιού** που θα λειτουργεί ως **κίνητρο**, που θα κάνει την ανακύκλωση πιο ενδιαφέρουσα, κυρίως για τους νέους.

-   Παροχή **διαφάνειας και ανταγωνιστικότητας**, ώστε οι πολίτες να βλέπουν την πρόοδό τους και να βελτιώνονται.

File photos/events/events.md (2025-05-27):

## Φωτογραφίες από την παρουσίαση του έργου στη 2η Γιορτή Δημιουργίας και Ψηφιακών Δεξιοτήτων "Ο Θε-ΤΑΛΩΣ συναντά τα e-trikala" και από την παρουσίαση στο σχολείο








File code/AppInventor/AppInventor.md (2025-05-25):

Εδώ θα βρείτε screenshots από το πρόγραμμα για Android με blocks, καθώς και screenshots από το design. Επίσης το αρχείο .apk εγκατάστασης σε android.

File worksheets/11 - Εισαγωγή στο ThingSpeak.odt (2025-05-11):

# Φύλλο Εργασίας 11

# Εισαγωγή στο ThingSpeak

Πηγές:

https://www.mathworks.com/help/thingspeak/getting-started-with-thingspeak.html

Το ThingSpeak είναι μια πλατφόρμα στο διαδίκτυο όπου μπορούμε να στείλουμε δεδομένα που αποθηκεύονται στο νέφος (cloud), αναπτύσσοντας έτσι εφαρμογές Internet of Things.

Αρχικά, κάνουμε λογαριασμό στο Thingspeak.com.

Κατόπιν:

- Μπαίνουμε στο λογαριασμό μας στο Thingspeak.com και δημιουργούμε ένα νέο κανάλι (New Channel)
- Δίνουμε ένα όνομα στο κανάλι
- Τσεκάρουμε και τα 8 πεδία και τα ονομάζουμε Person1, Person2 κοκ

Για να γράψουμε δεδομένα στο κανάλι, χρησιμοποιούμε το REST API ως εξής:

Σε έναν browser γράφουμε στη γραμμή διεύθυνσης:

https://api.thingspeak.com/update.json?api_key=<write_api_key>&field1=123

όπου αντικαθιστούμε το <write_api_key> με τον κωδικό που βρίσκουμε στην καρτέλα “API Keys” του καναλιού μας, και συμπληρώνουμε τα πεδία και τις τιμές που θέλουμε να αποθηκεύσουμε.

Ελέγχουμε τις τιμές στην καρτέλα “Private View” του καναλιού μας.

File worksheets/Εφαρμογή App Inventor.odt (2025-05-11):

### Ταξινόμηση λίστας:

http://ai2.appinventor.mit.edu/reference/concepts/pholo.html#sort

### Αλγόριθμος

Η διαδικασία retrieveData ανακαλεί τα δεδομένα από το ThingSpeak και τα αποθηκεύει σε μία λίστα με όνομα players, που αποτελείται από υπολίστες, όπου κάθε υπολίστα αποτελείται από το όνομα του παίκτη και τη βαθμολογία του, έχει δηλαδή η λίστα players τη μορφή:

[ [player1, 10],

[player2, 20],

[player3, 30],

[player8, 80] ]

Άρα πχ ο πρώτος παίκτης είναι στη θέση 1 της λίστας players, ενώ η βαθμολογία του 3ου παίκτη είναι στη θέση 2 της υπολίστας που είναι στη θέση 3 της λίστας players.

Στη συνέχεια η λίστα ταξινομείται με βάση τη βαθμολογία (δηλαδή το στοιχείο με index 2 κάθε υπολίστας) και δημιουργείται μια άλλη λίστα με όνομα sortedPlayers.

### Design


### Blocks


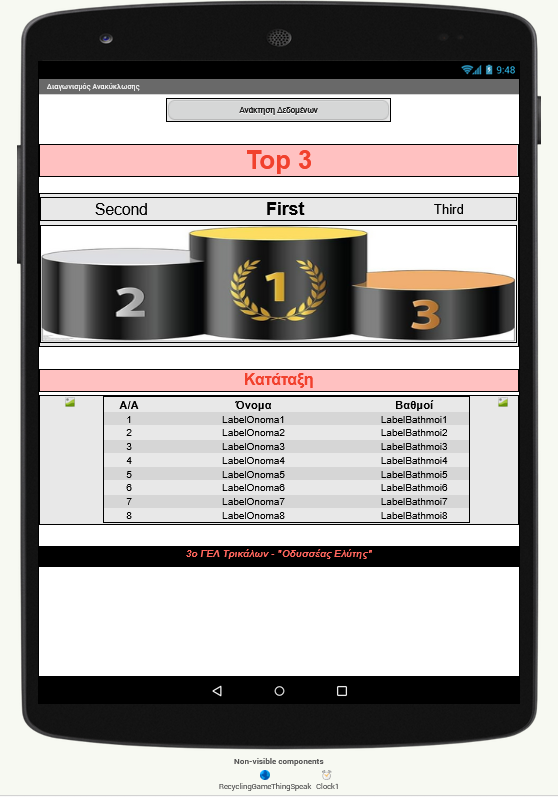
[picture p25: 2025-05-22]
code/AppInventor/ScreenShot_AppInventor_Design.png

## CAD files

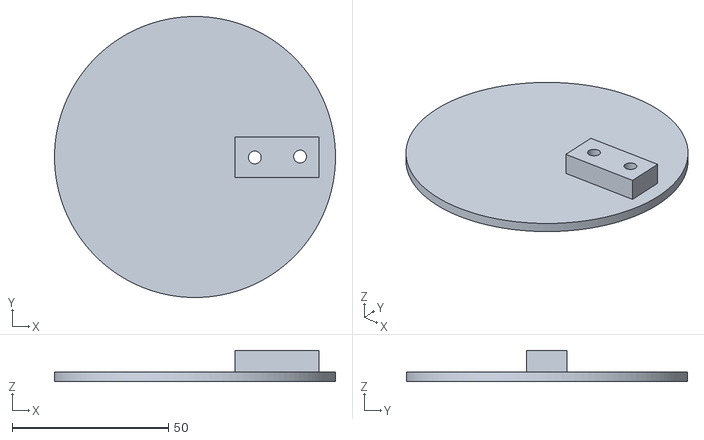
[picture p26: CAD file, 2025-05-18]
hardware-design/3D-objects/RecyclingChallengeScaleDisc.stl
90.0 x 90.0 x 10.0

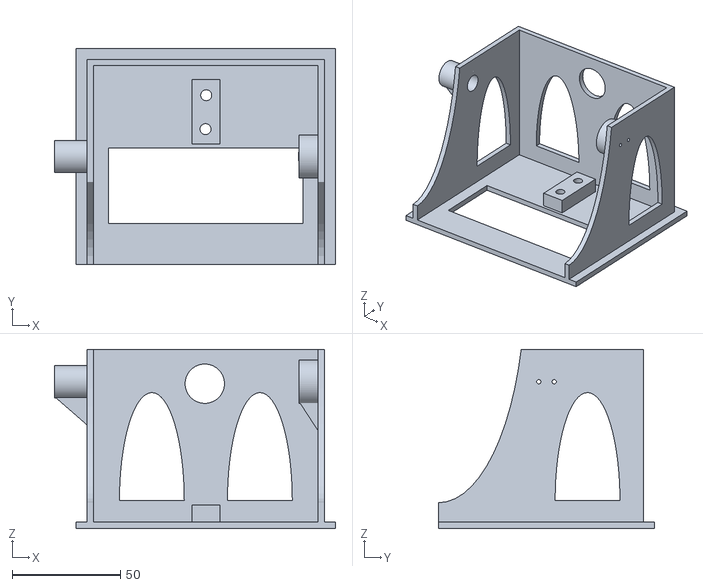
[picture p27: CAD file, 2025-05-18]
hardware-design/3D-objects/RecyclingChallengeCase.stl
130.1 x 100.0 x 83.0

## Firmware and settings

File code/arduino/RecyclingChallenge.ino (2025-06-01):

/***************************************************************
 *  3ο ΓΕΛ Τρικάλων - "Οδυσσέας Ελύτης"
 *  Ομάδα Ρομποτικής: Eco League
 *  Project: Διαγωνισμός Ανακύκλωσης
 *  Για τον 7ο Διαγωνισμό Ανοιχτών Τεχνολογιών στην Εκπαίδευση
 *	https://github.com/3lyktrik/ecoleague
 *
 *  Τρίκαλα - 2025
 ***************************************************************/

#include <SPI.h>
#include <MFRC522.h>
#include <LiquidCrystal_I2C.h>
#include <HX711.h>
#include <WiFiS3.h>
#include "secrets.h"
#include "persons.h"
#include <ThingSpeak.h> // always include thingspeak header file after other header files and custom macros

#define RST_PIN   5
#define SS_PIN    10
#define BUZZER_PIN  6
#define LASER_PIN   7
#define LDR_PIN     A0
#define METAL_PIN   8
#define LOADCELL_DOUT_PIN 2
#define LOADCELL_SCK_PIN  3

LiquidCrystal_I2C lcd(0x27,16,2);   // οθόνη LCD με 2 γραμμές και 16 χαρακτήρες, στην I2C διεύθυνση 0x27

String tagID = "";     // για το UID της κάρτας RFID

MFRC522 mfrc522(SS_PIN, RST_PIN);   // αναγνώστης καρτών RFID   

int metalVal = 0;   // αισθητήρας μετάλλων
int weight = 0;     // βάρος

bool metalDetected = false;
bool transparentDetected = false;
bool heavyDetected = false;

HX711 scale;    // πλακέτα (ενισχυτής) του αισθητήρα βάρους

char ssid[] = SECRET_SSID;   // WiFi SSID (name) 
char pass[] = SECRET_PASS;   // WiFi password
int status = WL_IDLE_STATUS;
WiFiClient  client;

// η διεύθυνση του thingspeak
char server[] = "api.thingspeak.com";
unsigned long myChannelNumber = SECRET_CH_ID;
const char *myWriteAPIKey = SECRET_WRITE_APIKEY;
const char *myReadAPIKey = SECRET_READ_APIKEY;

// οι 3 μετρητές για τα υλικά που ανακυκλώθηκαν
int metal = 0;      // ο αριθμός των μετάλλων που ανακυκλώθηκαν
int plastic = 0;    // ο αριθμός των πλαστικών που ανακυκλώθηκαν
int glass = 0;      // ο αριθμός των γυαλιών που ανακυκλώθηκαν

// η βαθμολογία που προκύπτει από τα υλικά που ανακυκλώθηκαν
int score = 0;

// για μέτρηση του χρόνου
unsigned long currentTime;
unsigned long previousTime = 0;

// η θέση του παίκτη στον πίνακα αντιστοίχισης ονομάτων-καρτών
int personFieldIndex;

void setup()
{
  pinMode(BUZZER_PIN, OUTPUT);
  pinMode(LASER_PIN, OUTPUT);
  pinMode(LDR_PIN, INPUT);
  pinMode(METAL_PIN, INPUT_PULLUP);

  Serial.begin(115200);

  SPI.begin(); // SPI bus
  mfrc522.PCD_Init(); // MFRC522

  lcd.init(); // lcd οθόνη
  lcd.backlight();
  // Print a message to the LCD.
  lcd.setCursor(0,0);
  lcd.print("3o GEL TRIKALON");
  lcd.setCursor(0,1);
  lcd.print("Odysseas Elytis");
  
  Serial.println("ΔΙΑΓΩΝΙΣΜΟΣ ΑΝΑΚΥΚΛΩΣΗΣ");
  
  scale.begin(LOADCELL_DOUT_PIN, LOADCELL_SCK_PIN);

  // ο παρακάτω συντελεστής υπολογίστηκε με το καλιμπράρισμα
  scale.set_scale(1091.32);
  scale.tare();   // reset the scale to 0
  delay(1000);

  // Σύνδεση στο WiFi
  ConnectToWiFi();
  
  // Initialize ThingSpeak
  ThingSpeak.begin(client);
}

void loop()
{
  lcd.setCursor(0,0);
  lcd.print(" Recycling Game ");
  lcd.setCursor(0,1);
  lcd.print("Place your card.");
  // Αναμονή για νέα κάρτα
  tagID = "";
  while( getID() )
  {
    tone(BUZZER_PIN, 1000); // Send sound signal...
    delay(500);             // ...for 0.5 sec
    noTone(BUZZER_PIN);     // Stop sound...

    score = 0;
    // αναζήτηση του UID της κάρτας στον αποθηκευμένο πίνακα
    int i = 0;
    bool found = false;
    while( i<PERSONS_NUMBER && !found )     // το PERSONS_NUMBER ορίζεται στο persons.h
    {
      if( tagID == cardsUIDs[i] )           // το cardUIDs ορίζεται στο persons.h
      {
        found = true;
        Serial.println(names[i]);           // το names ορίζεται στο persons.h
        lcd.clear();
        lcd.setCursor(0,0);
        lcd.print("Welcome");
        //int x = (16 - names[i].length()) div 2; // για στοίχιση στο κέντρο
        //lcd.setCursor(x,1);
        lcd.setCursor(8,0);
        lcd.print(names[i]);
        personFieldIndex = i+1; // ο πίνακας είναι από 0-7, ενώ τα fields του thingspeak απο 1-8
      }
      i++;
    }
    if( !found )
    {
      lcd.clear();
      lcd.setCursor(0,0);
      lcd.print(" Unknown Card...");
      delay(3000);
      break;
    }

    // Αναμονή για τοποθέτηση υλικού για ανακύκλωση
    lcd.setCursor(0,1);
    lcd.print("Place material..");
    Serial.println("Place material...");

    // Διάβασμα ζυγαριάς
    if( scale.is_ready() )
    {
      // όσο δεν τοποθετήθηκε υλικό στη ζυγαριά, περίμενε
      while( (weight=scale.get_units()) < 3 )
      {
        delay(500);
      }
      delay(1000);  // αναμονή για να ισορροπήσει ο αισθητήρας
      weight = scale.get_units();
      Serial.print("Weight=");
      Serial.println(weight);
    }

    // Ανίχνευση βάρους
    if( weight < 100 )
      heavyDetected = false;
    else
      heavyDetected = true;

    // Ανίχνευση μετάλλου
    metalVal = digitalRead(METAL_PIN);
    if( metalVal == LOW )
      metalDetected = true;
    else
      metalDetected = false;
  
    // Ανίχνευση διαφάνειας
    digitalWrite(LASER_PIN, HIGH);
    int counter = 0;    // μέτρηση 5 τιμών
    for( int i=0; i<5; i++)
    {
      int ldrStatus = analogRead(LDR_PIN);
      if( ldrStatus > 700 )
        counter++;
      delay(50);
    }
    digitalWrite(LASER_PIN, LOW);
    if( counter > 3 )
      transparentDetected = true;
    else
      transparentDetected = false;
  
    // Αποτελέσματα
    if( metalDetected )
    {
      Serial.println("Μέταλλο");
      lcd.setCursor(0,1);
      lcd.print("Metal: 50 pts   ");
      metal++;
    }
    else if( transparentDetected )
    {
      if( heavyDetected )
      {
        Serial.println("Γυαλί");
        lcd.setCursor(0,1);
        lcd.print("Glass: 30 pts   ");
        glass++;
      }
      else
      {
        Serial.println("Πλαστικό");
        lcd.setCursor(0,1);
        lcd.print("Plastic: 40 pts ");
        plastic++;
      }
    }
    else
    {
      Serial.println("Άλλο");
      lcd.setCursor(0,1);
      lcd.print("Other: 0 pts   ");
      delay(3000);
    }

    // έλεγχος του χρόνου
    currentTime = millis();
    // συγχρονισμός με το ThingSpeak κάθε 16 sec
    if( currentTime - previousTime >= 16000 )
    {
      // η βαθμολογία που προκύπτει από τις ανακυκλώσεις
      score = metal*50 + plastic*40 + glass*30;
  
      // αν υπάρχει νέο αντικείμενο, στείλε τη βαθμολογία στο ThingSpeak
      if( score != 0 )
      {
        if( personFieldIndex>=1 && personFieldIndex<=8 )
        {
          // Σύνδεση (ή επανασύνδεση) στο WiFi
          ConnectToWiFi();
    
          // διάβασε την τελευταία τιμή από το ThingSpeak, από το αντίστοιχο field
          int previousScore = ThingSpeak.readIntField(myChannelNumber, personFieldIndex);

          // Check the status of the read operation to see if it was successful
          int statusCode = ThingSpeak.getLastReadStatus();
          if(statusCode == 200)     // επιτυχής ανάγνωση από το ThingSpeak!
          {
            Serial.println("Successfully Reading ThingSpeak Score: " + String(previousScore));
            int x = ThingSpeak.writeField(myChannelNumber, personFieldIndex, score+previousScore, myWriteAPIKey);
            if(x == 200)      // επιτυχές γράψιμο στο ThingSpeak!  
            {
              Serial.println("Channel writing successful.");
              // μηδενισμός όλων των μετρητών και του σκορ
              score = metal = plastic = glass = 0;
            }
            else
            {
              Serial.println("Problem writing channel. HTTP error code " + String(x));
            }
          }
          else
          {
            Serial.println("Problem reading channel... HTTP error code " + String(statusCode));
          }
        }
        else
        {
          Serial.println("Ο παίκτης είναι εκτός ορίων του thingspeak");
          delay(1500);
          lcd.setCursor(0,1);
          lcd.print(" Not in players ");
          delay(2500);
        }
      }
  
      previousTime = currentTime;    
    }
  }
}

// Διάβασμα νέας κάρτας RFID
boolean getID()
{
  // Getting ready for Reading PICCs
  if( !mfrc522.PICC_IsNewCardPresent() )
  {
    return false;
  }
  if( !mfrc522.PICC_ReadCardSerial() )
  {
    return false;
  }
 
  tagID = "";
  for( int i = 0; i < mfrc522.uid.size; i++ )
  {
    tagID.concat(String(mfrc522.uid.uidByte[i], HEX)); // Adds the 4 bytes in a single String variable
  }
  tagID.toUpperCase();
  mfrc522.PICC_HaltA(); // Stop reading
  return true;
}


void ConnectToWiFi()
{
  // Connect or reconnect to WiFi
  if(WiFi.status() != WL_CONNECTED)
  {
    Serial.print("Attempting to connect to SSID: ");
    Serial.println(SECRET_SSID);
    while(WiFi.status() != WL_CONNECTED)
    {
      WiFi.begin(ssid, pass); // Connect to WPA/WPA2 network
      Serial.print(".");
      delay(5000);     
    } 
    Serial.println("\nConnected.");
  }
}
